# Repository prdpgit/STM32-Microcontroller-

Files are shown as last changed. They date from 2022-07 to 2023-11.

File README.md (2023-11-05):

# STM32 Microcontroller 
 
The designed PCB features an STM32F4RTG6 microcontroller which is part of the STM32F4 series known for its high performance and with floating point unit (FPU) that supports ARM Cortex-M4 core. The board integrates an MPU6050, which is a popular 6-axis MotionTracking device combining a 3-axis gyroscope and a 3-axis accelerometer.

## Microcontroller Core:

STM32F4RTG6: ARM Cortex-M4 core with FPU, running at high frequencies, capable of driving complex applications that require floating-point calculations and advanced control algorithms.
Sensors:

MPU6050: Offers onboard Digital Motion Processing™ (DMP™) capable of processing complex 6-axis MotionFusion algorithms. The sensors communicate via I2C protocol, which is set up on the STM32F4 microcontroller.
Power Supply:

The board appears to have a +5V input power supply, with onboard voltage regulation to provide +3.3V needed by both the STM32 microcontroller and the MPU6050 sensor.
Voltage regulators (like AMS1117-3.3) are used to step down the voltage.
Various capacitors are placed near power inputs and voltage regulators to stabilize the power supply and reduce noise.
Connectivity:

The microcontroller’s I/O pins are brought out to headers, providing the ability to connect to other peripherals and sensors.
The schematic shows decoupling capacitors and pull-up resistors on I2C lines which are critical for signal integrity.
Programming and Debugging Interface:

There appears to be a programming interface, possibly using Serial Wire Debug (SWD), which is standard for STM32 devices. This allows for programming and debugging of the microcontroller directly on the board.
Oscillator:

A crystal oscillator is used for providing an accurate clock signal to the STM32F4 microcontroller.
Load capacitors are connected to the crystal to ensure proper oscillation.
General PCB Design Notes:

The schematic is organized into functional blocks, which simplifies the complexity and helps in understanding the circuit.
Each IC has decoupling capacitors close to the power supply pins to reduce power supply noise and for maintaining signal integrity.
The use of pull-up resistors on the reset line and buttons indicates attention to proper microcontroller reset and user input handling.

## Schematic:
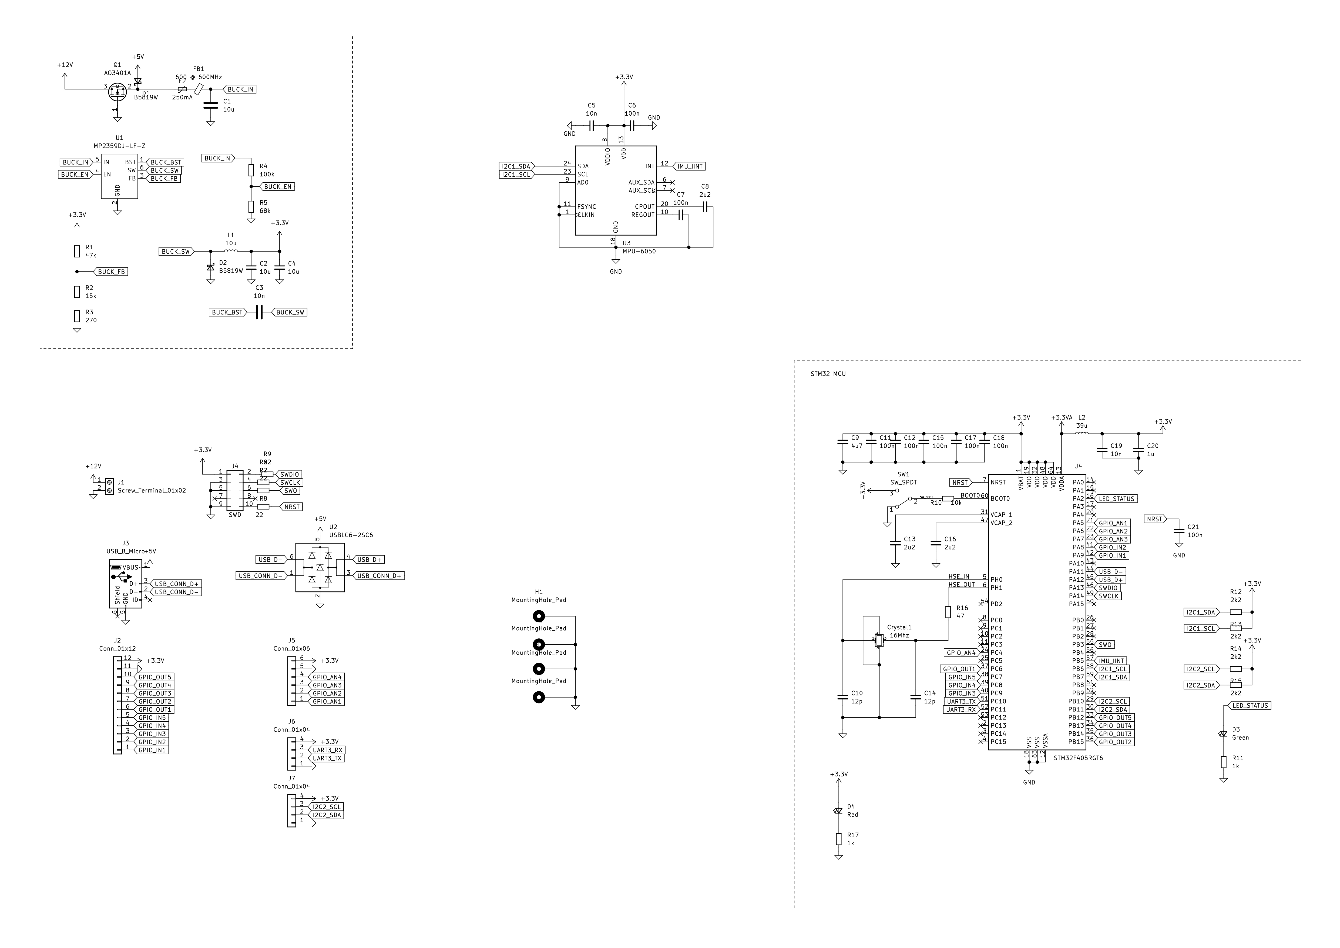
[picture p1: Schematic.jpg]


## PCB layout
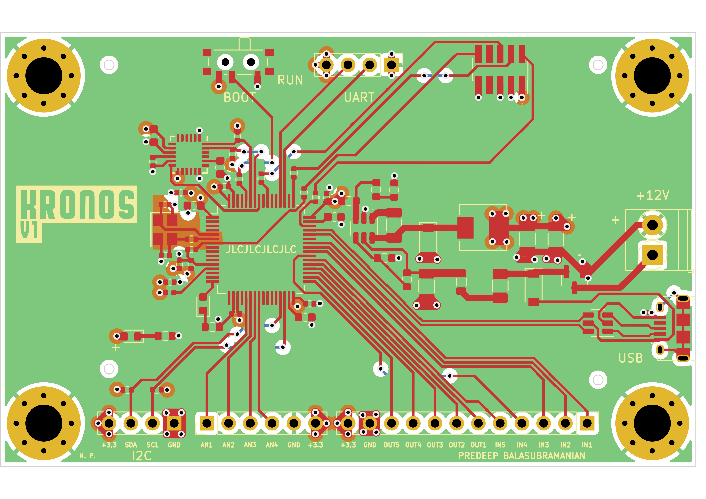
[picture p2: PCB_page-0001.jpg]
PCB layout


## 3D PCB render
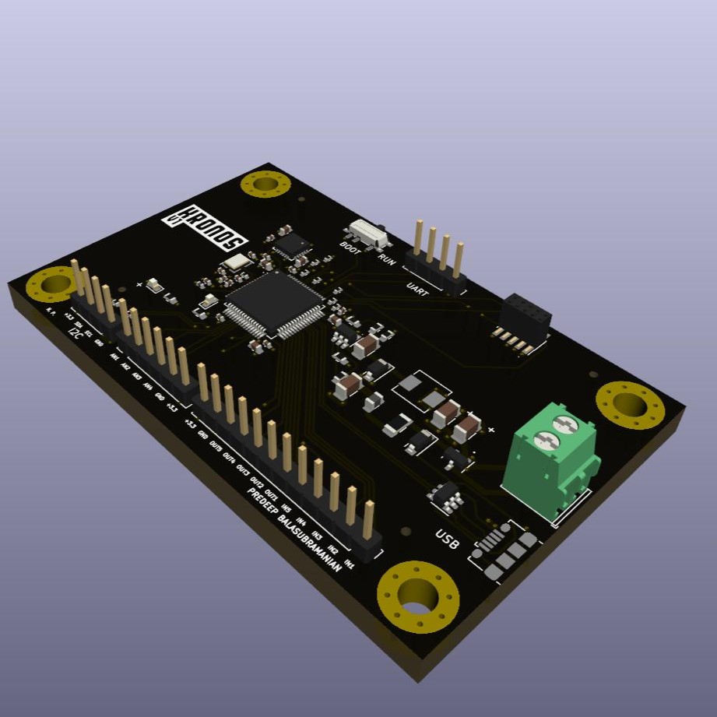
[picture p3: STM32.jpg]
PCB 3D1

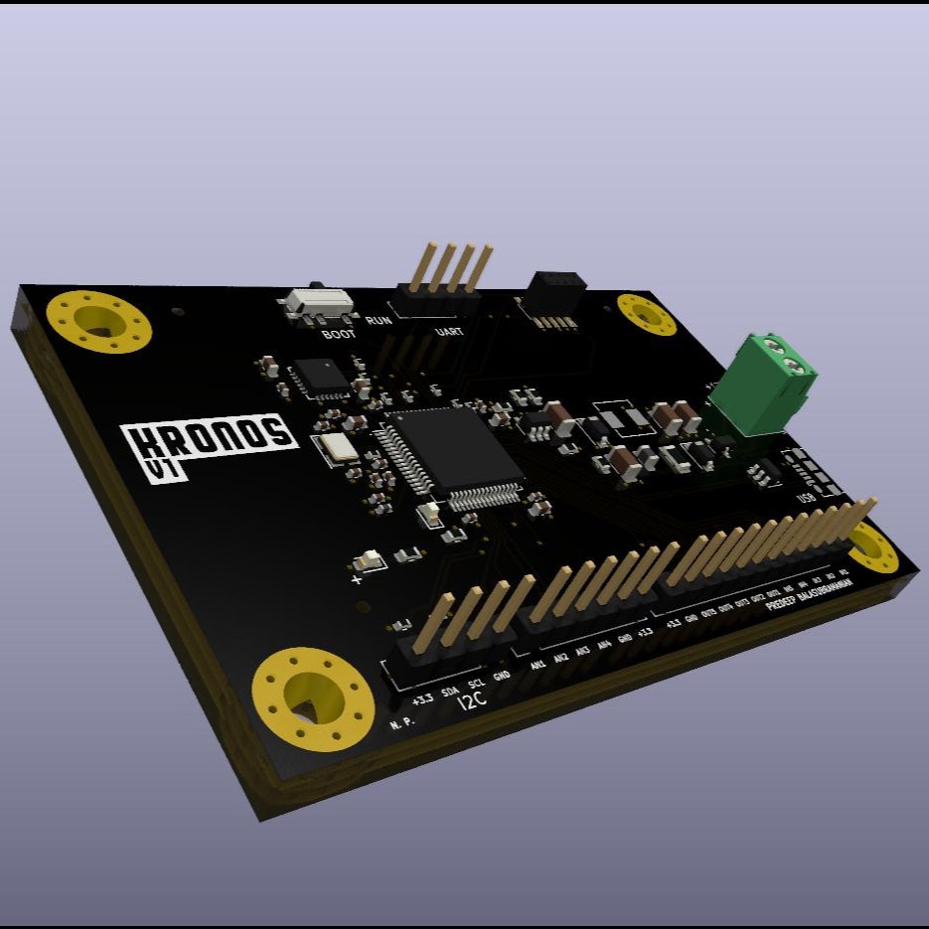
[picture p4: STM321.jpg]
PCB 3D2


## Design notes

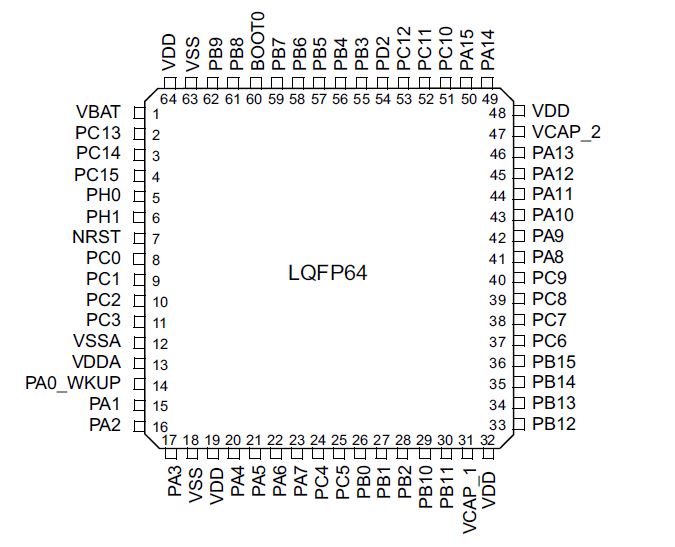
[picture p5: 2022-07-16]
STM32_pinout.JPG

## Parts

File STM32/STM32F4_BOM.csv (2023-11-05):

Comment | Designator | Footprint | JLCPCB Part #
10u | C1 | Capacitor_SMD:C_1206_3216Metric | C1954312
10u | C2, C4 | Capacitor_SMD:C_1206_3216Metric | C1954312
10n | C3 | Capacitor_SMD:C_1206_3216Metric | C77497
10n | C5 | Capacitor_SMD:C_0603_1608Metric | C2835533
100n | C6, C7, C11, C12, C15, C17, C18, C21 | Capacitor_SMD:C_0402_1005Metric | C361203
2u2 | C8, C13, C16 | Capacitor_SMD:C_0603_1608Metric | C1953313
4u7 | C9 | Capacitor_SMD:C_0603_1608Metric | C2844393
12p | C10, C14 | Capacitor_SMD:C_0402_1005Metric | C76700
10n | C19 | Capacitor_SMD:C_0402_1005Metric | C386111
1u | C20 | Capacitor_SMD:C_0402_1005Metric | C913556
16Mhz | Crystal1 | Crystal:Crystal_SMD_3225-4Pin_3.2x2.5mm | C160456
B5819W | D1, D2 | Diode_SMD:D_SOD-123 | C779771
Green | D3 | LED_SMD:LED_0603_1608Metric | C397049
Red | D4 | LED_SMD:LED_0603_1608Metric | C90692
250mA | F2 | Fuse:Fuse_1206_3216Metric | C369159
600 @ 600MHz | FB1 | Inductor_SMD:L_0805_2012Metric | C1017
MountingHole_Pad | H1, H2, H3, H4 | MountingHole:MountingHole_4.3mm_M4_Pad_Via
Screw_Terminal_01x02 | J1 | TerminalBlock_Phoenix:TerminalBlock_Phoenix_PT-1,5-2-3.5-H_1x02_P3.50mm_Horizontal
Conn_01x12 | J2 | Connector_PinHeader_2.54mm:PinHeader_1x12_P2.54mm_Vertical
USB_B_Micro | J3 | Connector_USB:USB_Micro-B_Amphenol_10118194_Horizontal
SWD | J4 | Connector_PinSocket_1.27mm:PinSocket_2x05_P1.27mm_Vertical_SMD
Conn_01x06 | J5 | Connector_PinHeader_2.54mm:PinHeader_1x06_P2.54mm_Vertical
Conn_01x04 | J6, J7 | Connector_PinHeader_2.54mm:PinHeader_1x04_P2.54mm_Vertical
10u | L1 | Inductor_SMD:L_Sunlord_MWSA0518_5.4x5.2mm | C150031
39u | L2 | Inductor_SMD:L_0402_1005Metric | C26443
AO3401A | Q1 | Package_TO_SOT_SMD:SOT-23 | C306862
47k | R1 | Resistor_SMD:R_0603_1608Metric | C227501
15k | R2 | Resistor_SMD:R_0603_1608Metric | C3152125
270 | R3 | Resistor_SMD:R_0603_1608Metric | C667461
100k | R4 | Resistor_SMD:R_0603_1608Metric | C667752
68k | R5 | Resistor_SMD:R_0603_1608Metric | C912142
22 | R6, R7, R8, R9 | Resistor_SMD:R_0402_1005Metric | C174144
10k | R10 | Resistor_SMD:R_0402_1005Metric | C328298
1k | R11, R17 | Resistor_SMD:R_0603_1608Metric | C269704
2k2 | R12, R13, R14, R15 | Resistor_SMD:R_0402_1005Metric | C3017487
47 | R16 | Resistor_SMD:R_0402_1005Metric | C1096
SW_SPDT | SW1 | Button_Switch_SMD:SW_SPDT_PCM12
MP2359DJ-LF-Z | U1 | Package_TO_SOT_SMD:SOT-23-6 | C14259
USBLC6-2SC6 | U2 | Package_TO_SOT_SMD:SOT-23-6
MPU-6050 | U3 | Sensor_Motion:InvenSense_QFN-24_4x4mm_P0.5mm | C24112
STM32F405RGT6 | U4 | Package_QFP:LQFP-64_10x10mm_P0.5mm | C15742

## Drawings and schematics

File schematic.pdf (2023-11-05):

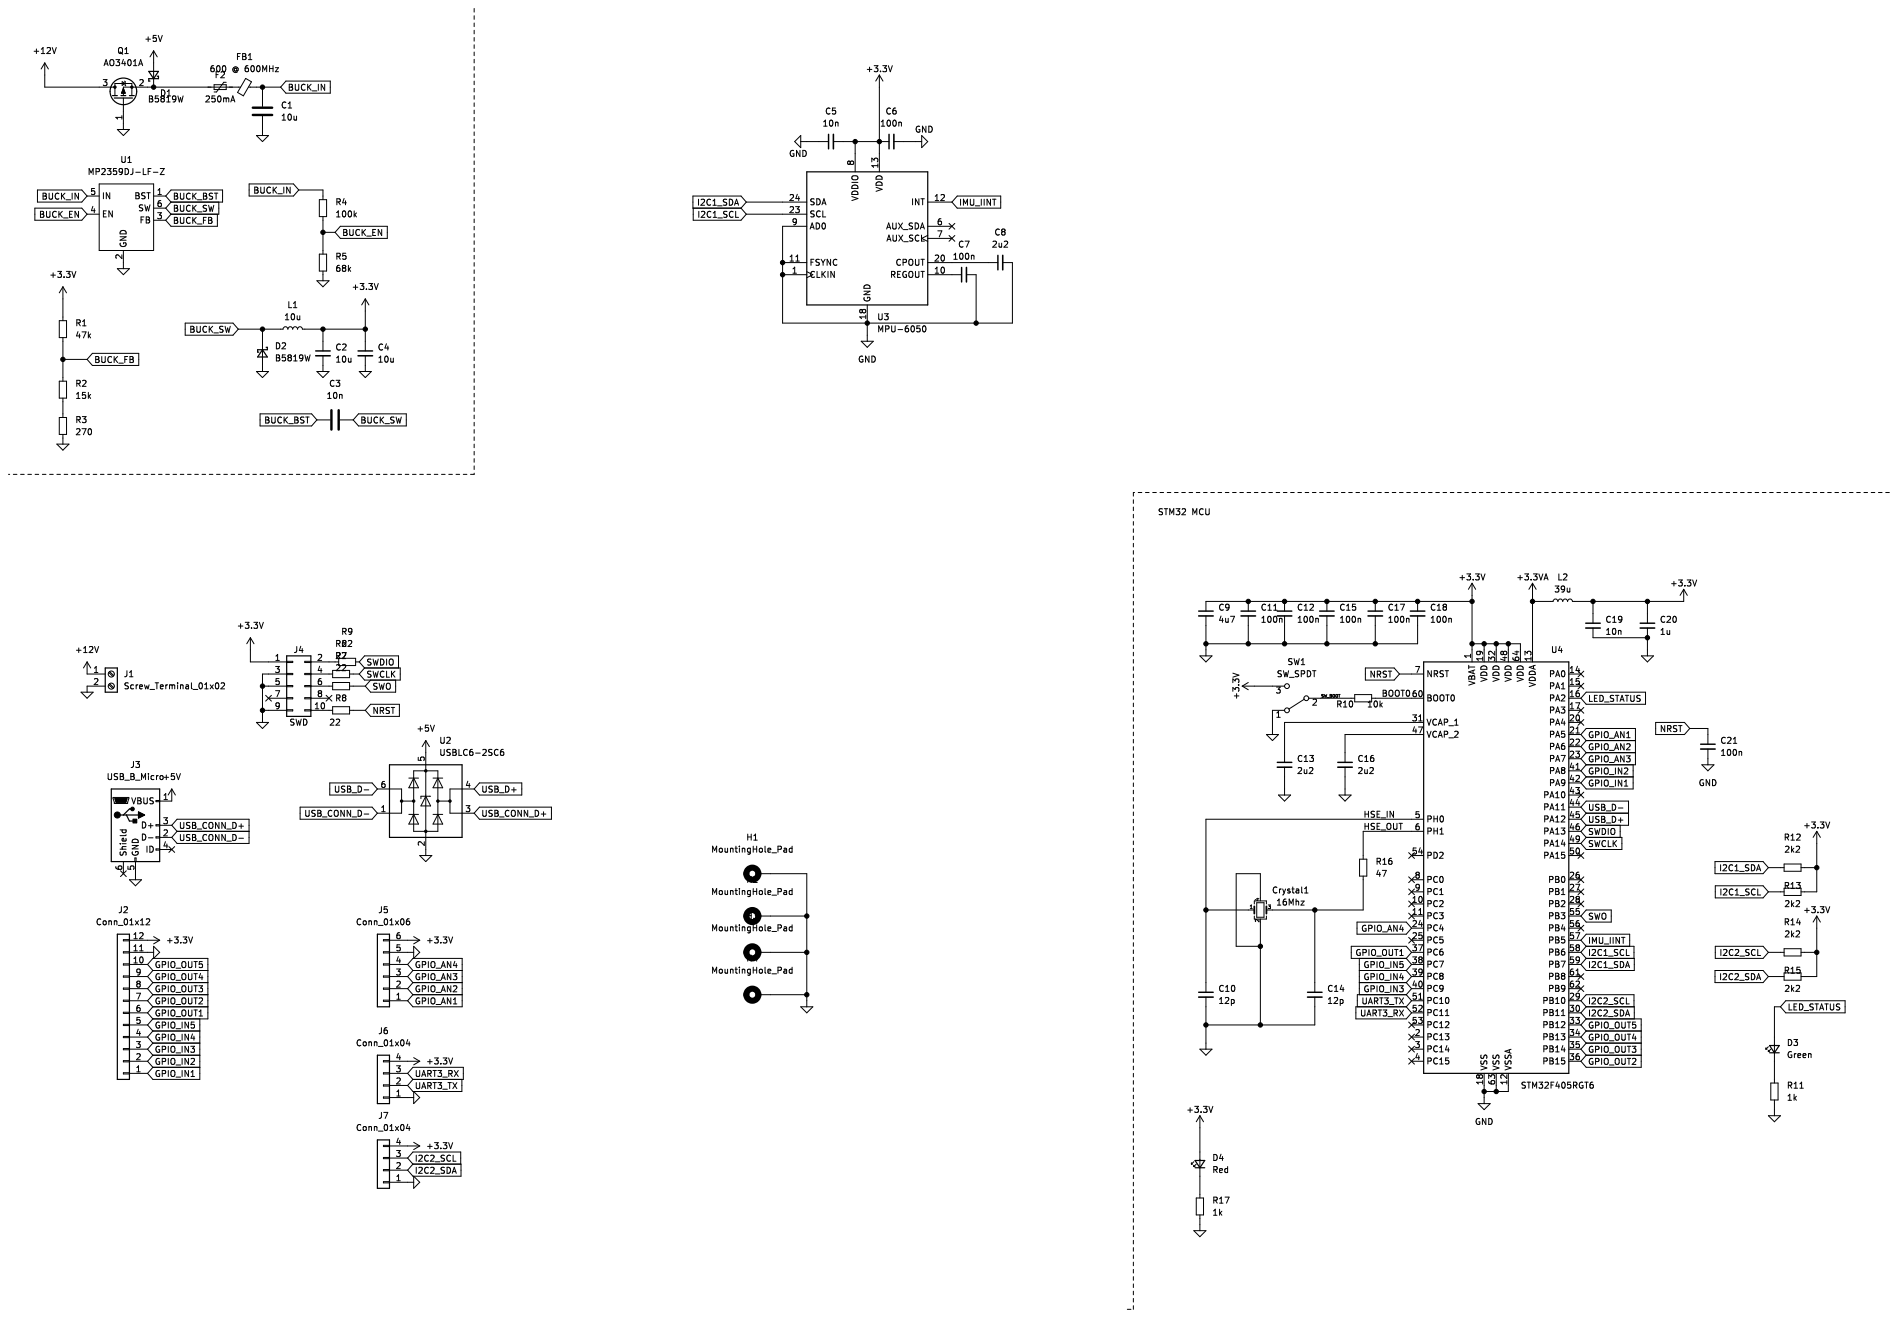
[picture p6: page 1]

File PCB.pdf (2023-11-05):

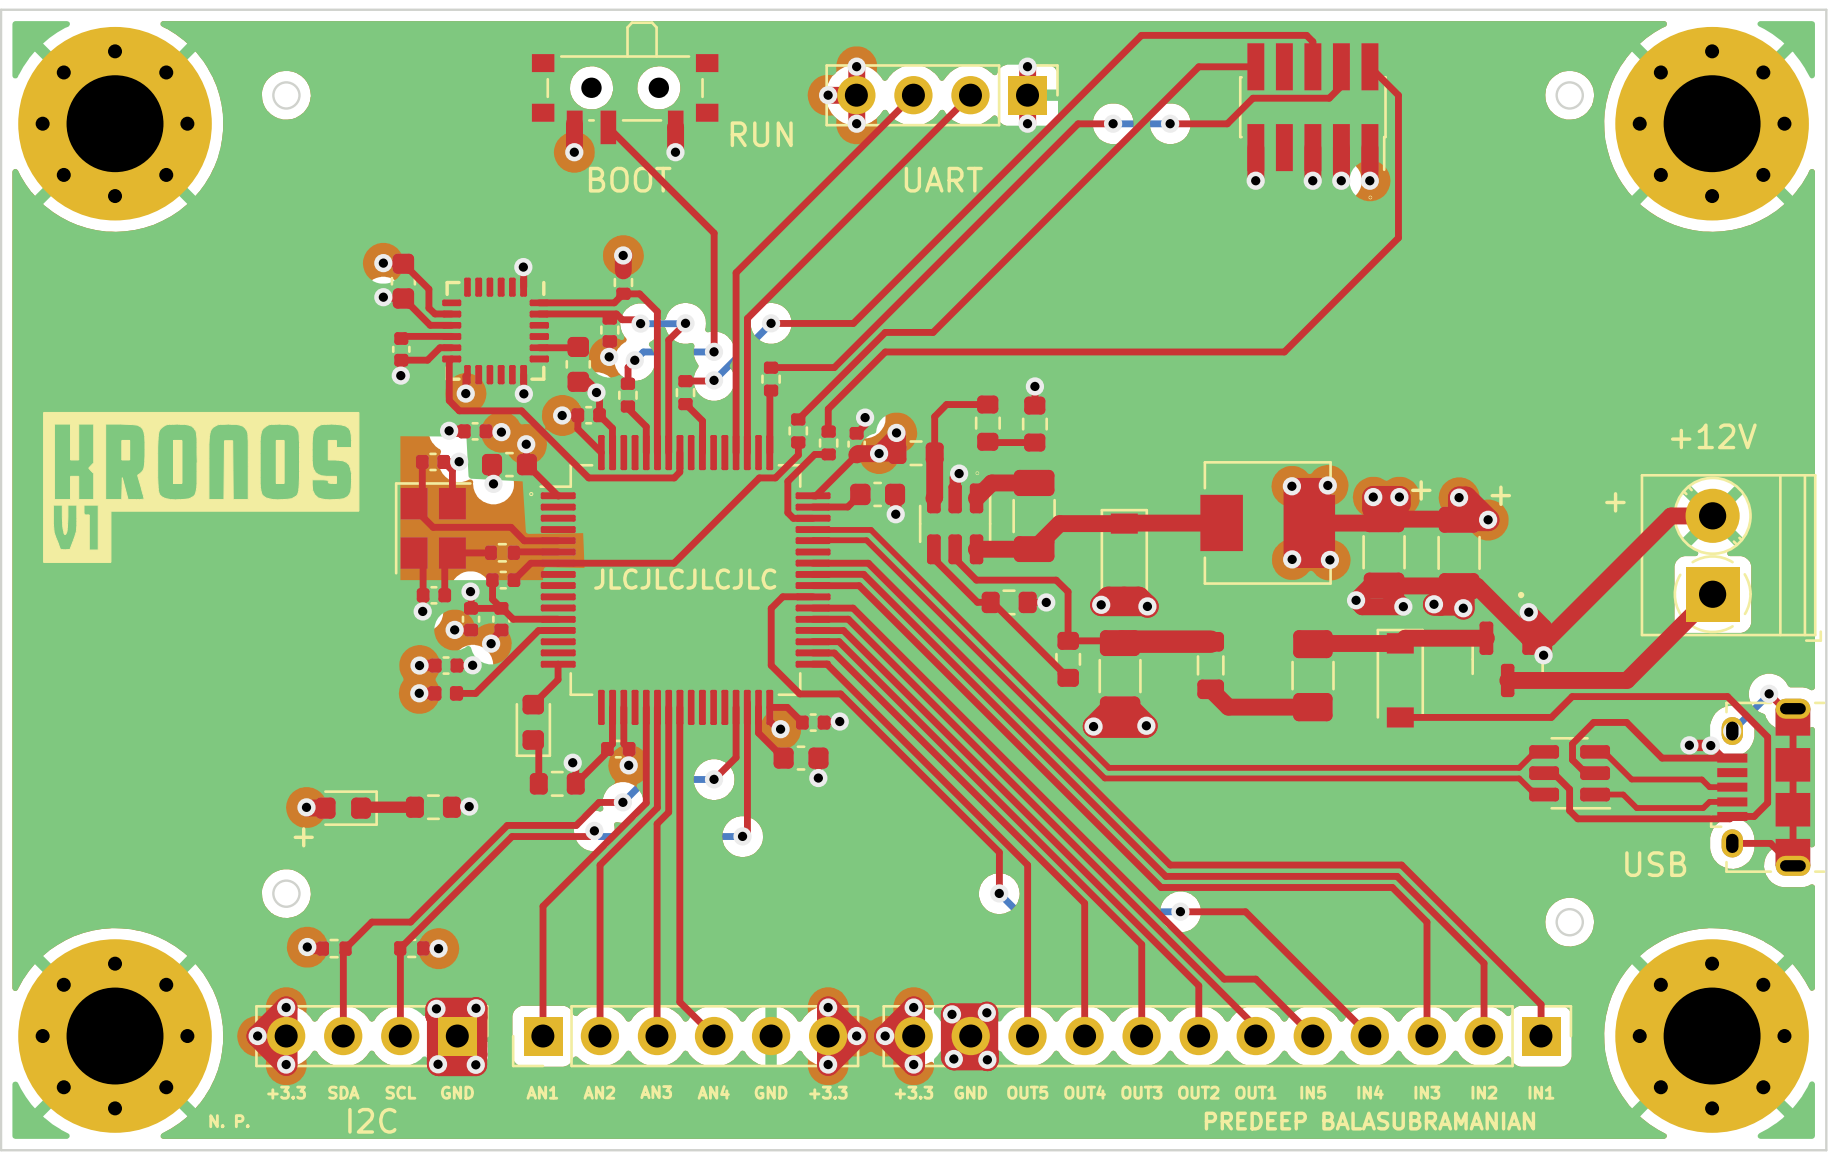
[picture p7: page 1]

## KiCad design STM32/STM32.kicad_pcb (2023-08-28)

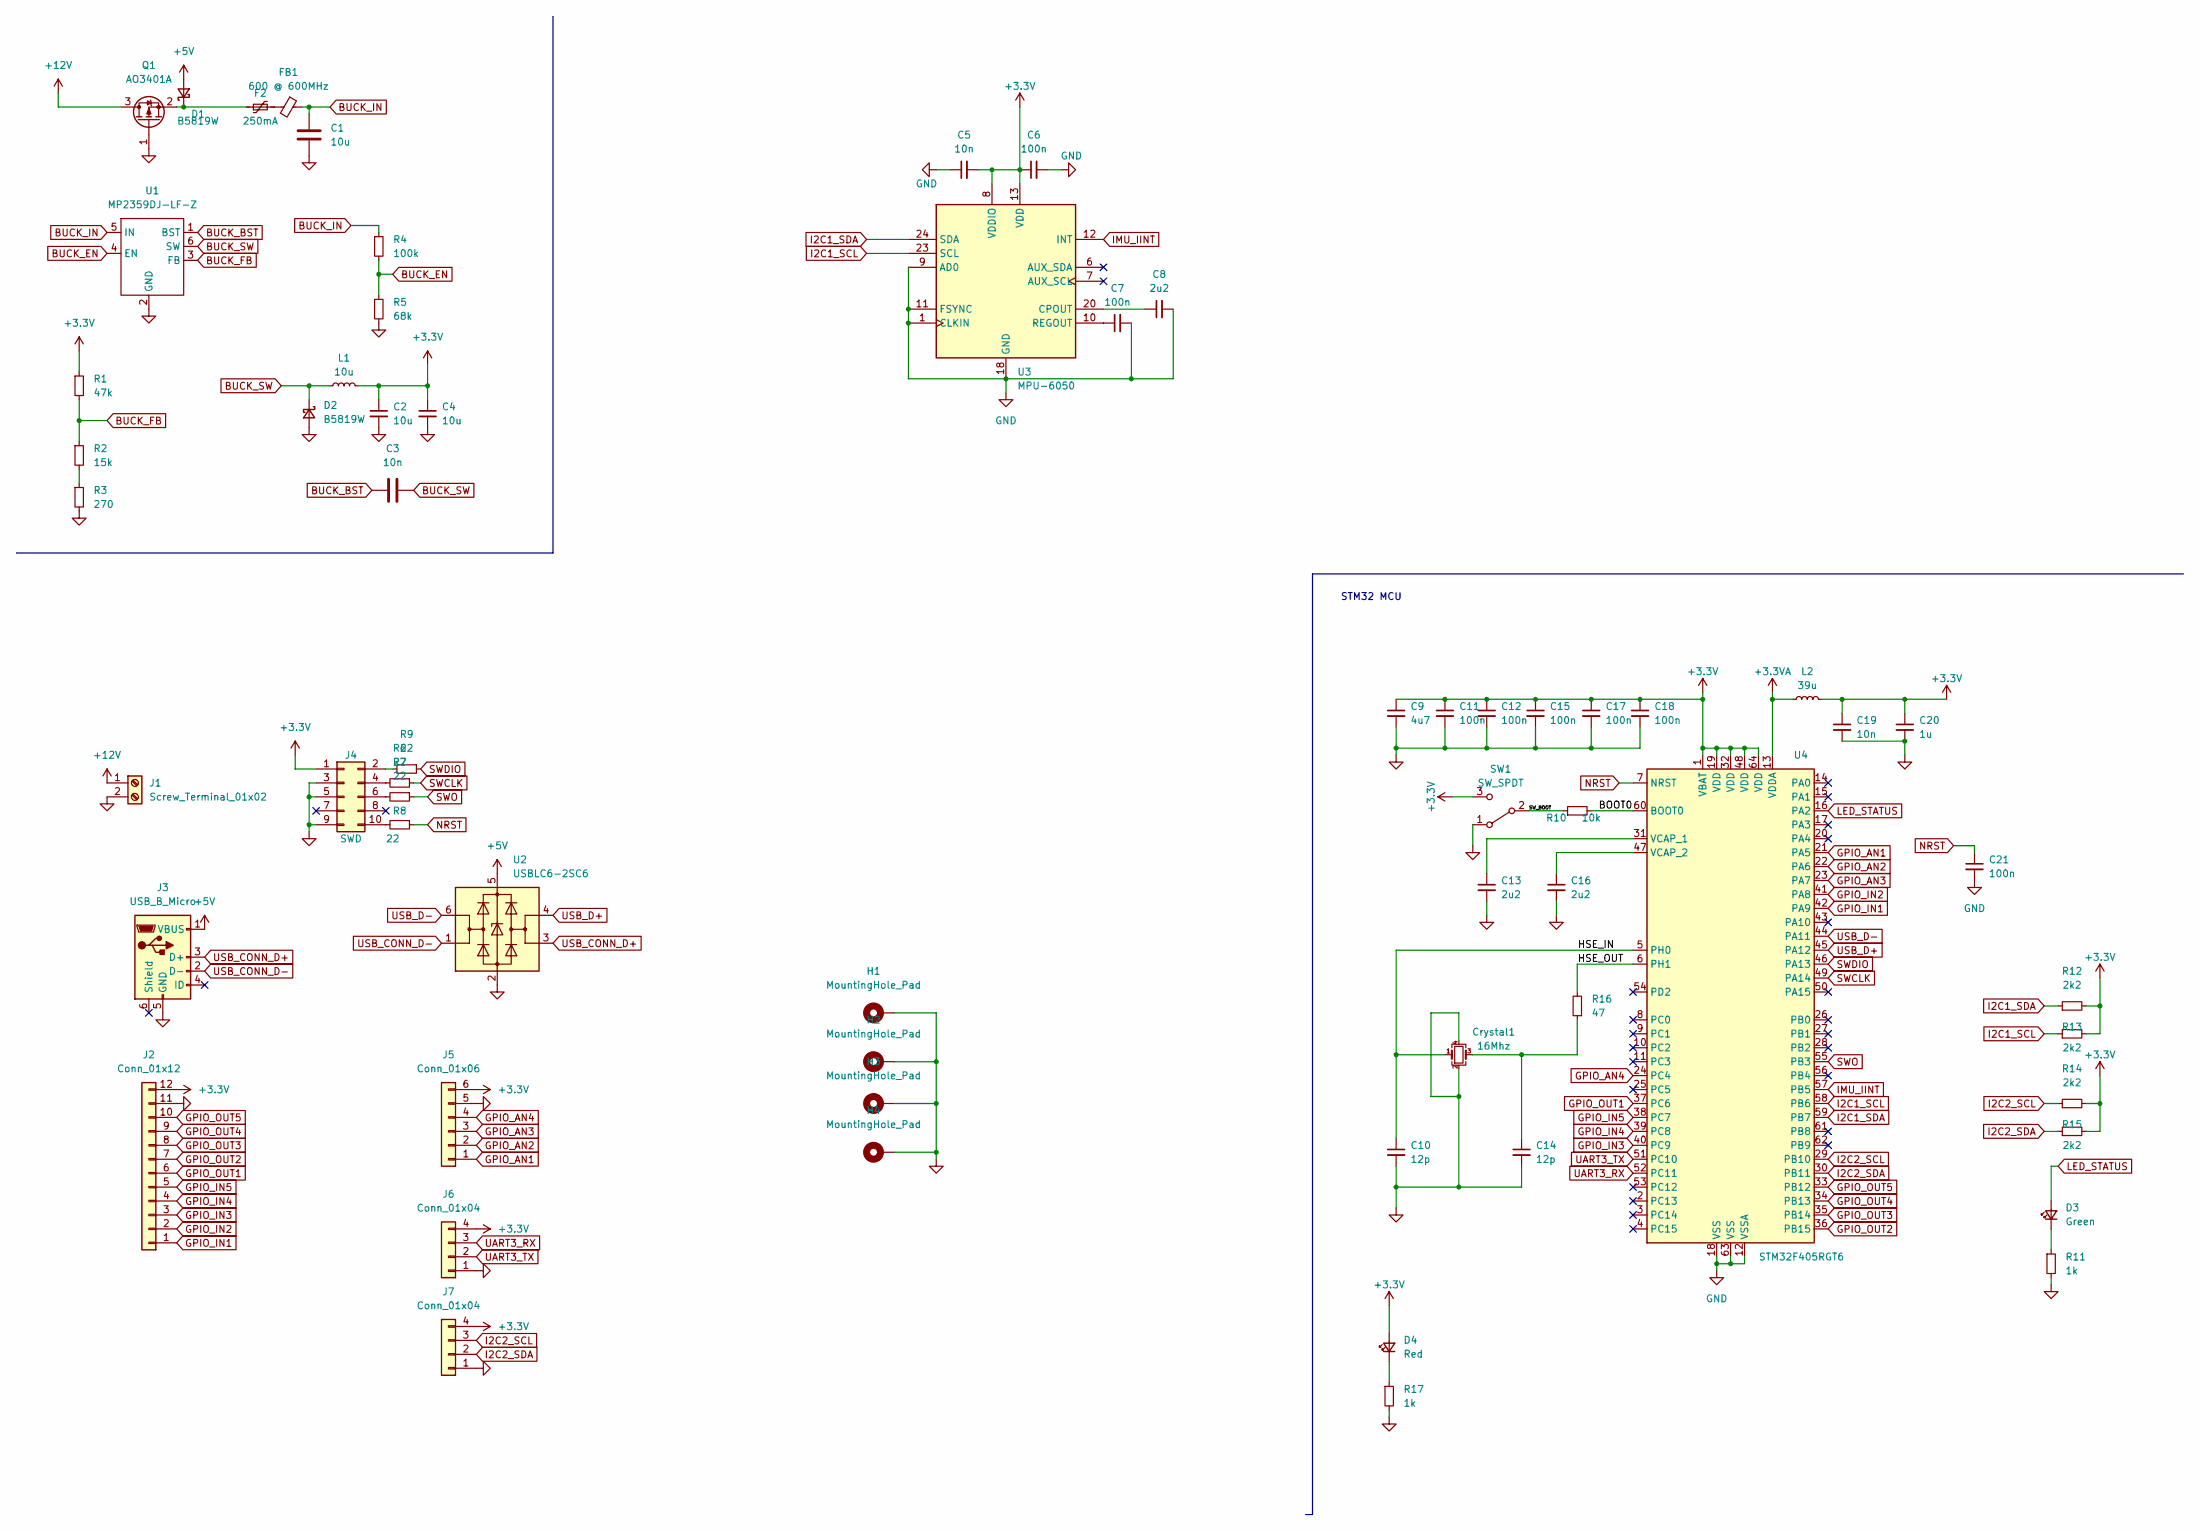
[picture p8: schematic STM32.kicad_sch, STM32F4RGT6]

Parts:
C1, C2, C4: 10u; C_1206_3216Metric; LCSC Part # C1954312
C3: 10n; C_1206_3216Metric; LCSC Part # C77497
C5: 10n; C_0603_1608Metric; LCSC Part # C2835533
C6, C7, C11, C12, C15, C17, C18, C21: 100n; C_0402_1005Metric; LCSC Part # C361203
C8, C13, C16: 2u2; C_0603_1608Metric; LCSC Part # C1953313
C9: 4u7; C_0603_1608Metric; LCSC Part # C2844393
C10, C14: 12p; C_0402_1005Metric; LCSC Part # C3876622
C19: 10n; C_0402_1005Metric; LCSC Part # C386111
C20: 1u; C_0402_1005Metric; LCSC Part # C1954072
Crystal1: 16Mhz; Crystal_SMD_3225-4Pin_3.2x2.5mm; LCSC Part # C160456
D1, D2: B5819W; D_SOD-123; LCSC Part # C779771
D3: Green; LED_0603_1608Metric; LCSC Part # C3148192
D4: Red; LED_0603_1608Metric; LCSC Part # C84263
F2: 250mA; Fuse_1206_3216Metric; LCSC Part # C369159
FB1: 600 @ 600MHz; L_0805_2012Metric; LCSC Part # C1017
H1, H2, H3, H4: MountingHole_Pad; MountingHole_4.3mm_M4_Pad_Via
J1: Screw_Terminal_01x02; TerminalBlock_Phoenix_PT-1,5-2-3.5-H_1x02_P3.50mm_Horizontal
J2: Conn_01x12; PinHeader_1x12_P2.54mm_Vertical
J3: USB_B_Micro; USB_Micro-B_Amphenol_10118194_Horizontal
J4: SWD; PinSocket_2x05_P1.27mm_Vertical_SMD
J5: Conn_01x06; PinHeader_1x06_P2.54mm_Vertical
J6, J7: Conn_01x04; PinHeader_1x04_P2.54mm_Vertical
L1: 10u; L_Sunlord_MWSA0518_5.4x5.2mm; LCSC Part # C139506
L2: 39u; L_0402_1005Metric; LCSC Part # C26443
Q1: AO3401A; SOT-23; LCSC Part # C306862
R1: 47k; R_0603_1608Metric; LCSC Part # C227501
R2: 15k; R_0603_1608Metric; LCSC Part # C3152125
R3: 270; R_0603_1608Metric; LCSC Part # C667461
R4: 100k; R_0603_1608Metric; LCSC Part # C667752
R5: 68k; R_0603_1608Metric; LCSC Part # C912142
R6, R7, R8, R9: 22; R_0402_1005Metric; LCSC Part # C174144
R10: 10k; R_0402_1005Metric; LCSC Part # C328298
R11, R17: 1k; R_0603_1608Metric; LCSC Part # C269704
R12, R13, R14, R15: 2k2; R_0402_1005Metric; LCSC Part # C3017487
R16: 47; R_0402_1005Metric; LCSC Part # C1096
SW1: SW_SPDT; SW_SPDT_PCM12
U1: MP2359DJ-LF-Z; SOT-23-6; LCSC Part # C14259
U2: USBLC6-2SC6; SOT-23-6
U3: MPU-6050; InvenSense_QFN-24_4x4mm_P0.5mm; LCSC Part # C24112
U4: STM32F405RGT6; LQFP-64_10x10mm_P0.5mm; LCSC Part # C15742

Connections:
+3.3V: C2.1, C4.1, C5.2, C6.1, C9.1, C11.1, C12.1, C15.1, C17.1, C18.1, C19.1, C20.1, D4.2 (A), J2.12, J4.1, J5.6, J6.4, J7.4, L1.2, L2.2, R1.1, R12.2, R13.2, R14.2, R15.2, SW1.3 (C), U3.8 (VDDIO), U3.13 (VDD), U4.1 (VBAT), U4.19 (VDD), U4.32 (VDD), U4.48 (VDD), U4.64 (VDD)
+3.3VA: L2.1, U4.13 (VDDA)
+5V: D1.2 (A), J3.1 (VBUS), U2.5 (VBUS)
+12V: J1.1, Q1.3 (D)
/BOOT0: R10.2, U4.60 (BOOT0)
/HSE_IN: C10.1, Crystal1.1, U4.5 (PH0)
/HSE_OUT: R16.2, U4.6 (PH1)
/SW_BOOT: R10.1, SW1.2 (B)
BUCK_BST: C3.1, U1.1 (BST)
BUCK_EN: R4.2, R5.1, U1.4 (EN)
BUCK_FB: R1.2, R2.1, U1.3 (FB)
BUCK_IN: C1.1, FB1.1, R4.1, U1.5 (IN)
BUCK_SW: C3.2, D2.1 (K), L1.1, U1.6 (SW)
GND: C1.2, C2.2, C4.2, C5.1, C6.2, C7.2, C8.2, C9.2, C10.2, C11.2, C12.2, C13.2, C14.2, C15.2, C16.2, C17.2, C18.2, C19.2, C20.2, C21.2, Crystal1.2, Crystal1.4, D2.2 (A), H1.1, H2.1, H3.1, H4.1, J1.2, J2.11, J3.5 (GND), J4.3, J4.5, J4.9, J5.5, J6.1, J7.1, Q1.1 (G), R3.2, R5.2, R11.2, R17.2, SW1.1 (A), U1.2 (GND), U2.2 (GND), U3.1 (CLKIN), U3.9 (AD0), U3.11 (FSYNC), U3.18 (GND), U4.12 (VSSA), U4.18 (VSS), U4.63 (VSS)
GPIO_AN1: J5.1, U4.21 (PA5)
GPIO_AN2: J5.2, U4.22 (PA6)
GPIO_AN3: J5.3, U4.23 (PA7)
GPIO_AN4: J5.4, U4.24 (PC4)
GPIO_IN1: J2.1, U4.42 (PA9)
GPIO_IN2: J2.2, U4.41 (PA8)
GPIO_IN3: J2.3, U4.40 (PC9)
GPIO_IN4: J2.4, U4.39 (PC8)
GPIO_IN5: J2.5, U4.38 (PC7)
GPIO_OUT1: J2.6, U4.37 (PC6)
GPIO_OUT2: J2.7, U4.36 (PB15)
GPIO_OUT3: J2.8, U4.35 (PB14)
GPIO_OUT4: J2.9, U4.34 (PB13)
GPIO_OUT5: J2.10, U4.33 (PB12)
I2C1_SCL: R13.1, U3.23 (SCL), U4.58 (PB6)
I2C1_SDA: R12.1, U3.24 (SDA), U4.59 (PB7)
I2C2_SCL: J7.3, R14.1, U4.29 (PB10)
I2C2_SDA: J7.2, R15.1, U4.30 (PB11)
IMU_IINT: U3.12 (INT), U4.57 (PB5)
LED_STATUS: D3.2 (A), U4.16 (PA2)
NRST: C21.1, R8.1, U4.7 (NRST)
unnamed: C7.1, U3.10 (REGOUT)
unnamed: C8.1, U3.20 (CPOUT)
unnamed: C13.1, U4.31 (VCAP_1)
unnamed: C14.1, Crystal1.3, R16.1
unnamed: C16.1, U4.47 (VCAP_2)
unnamed: D1.1 (K), F2.1, Q1.2 (S)
unnamed: D3.1 (K), R11.1
unnamed: D4.1 (K), R17.1
unnamed: F2.2, FB1.2
unnamed: J4.2, R9.2
unnamed: J4.4, R6.2
unnamed: J4.6, R7.2
unnamed: J4.10, R8.2
unnamed: R2.2, R3.1
SWCLK: R6.1, U4.49 (PA14)
SWDIO: R9.1, U4.46 (PA13)
SWO: R7.1, U4.55 (PB3)
UART3_RX: J6.3, U4.52 (PC11)
UART3_TX: J6.2, U4.51 (PC10)
USB_CONN_D+: J3.3 (D+), U2.3 (I/O2)
USB_CONN_D-: J3.2 (D-), U2.1 (I/O1)
USB_D+: U2.4 (I/O2), U4.45 (PA12)
USB_D-: U2.6 (I/O1), U4.44 (PA11)

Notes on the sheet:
STM32 MCU

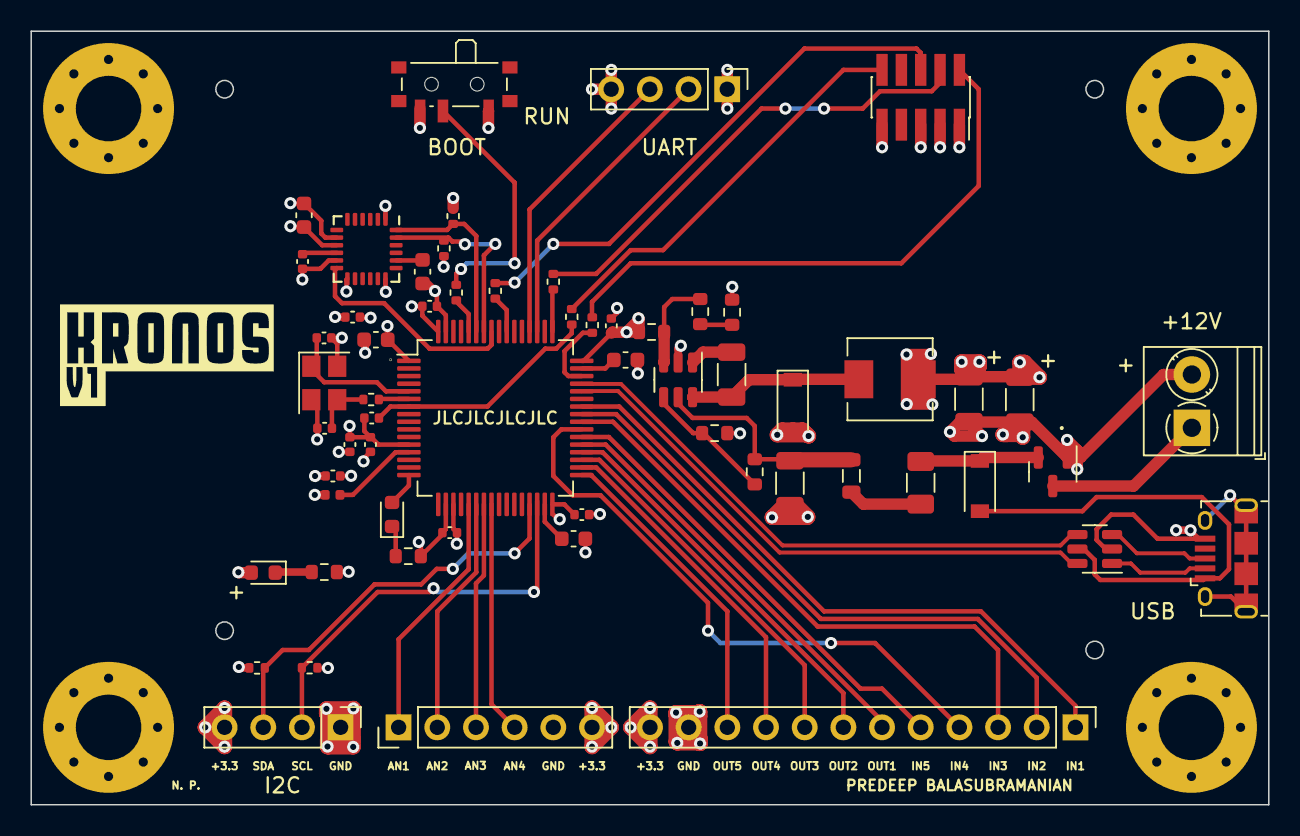
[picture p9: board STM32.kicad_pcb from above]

Board: 4 copper layers, 81.3 x 50.8 mm, 64 parts (0 on the bottom side), 58 nets.

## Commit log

2022-07-16 New files
    New files added
    [STM32.kicad_sch]
2022-07-17 update
    NRST and BOOT0
    [STM32.kicad_sch]
2022-07-18 Schematics update
    New files and schematics
    [STM32.kicad_sch]
2022-09-14 Update STM32.kicad_sch
    changes
    [STM32.kicad_sch]
